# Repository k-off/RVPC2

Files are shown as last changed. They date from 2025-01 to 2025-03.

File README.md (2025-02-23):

# RVPC2

Inspired by [OLIMEX RVPC](https://github.com/OLIMEX/RVPC) project, I decided to create a #higher-faster-stronger version.

Key differences:

|Feature|V1|V2|
|-|-|-|
|**MCU**|||
|Model|CH32V003F4P6|CH32X035G8R6|
|Pins|8|28|
|RAM|2k|20k|
|ROM|16k|64k|
|USB| X | **V** |
|**Display**|||
|Color|mono (1-bit)| 8 (3-bit)|
|Communication| X | **V** |
|**Ports**|||
|PS2| **V** | X |
|USB| X | **2.0 FS** |
|Audio| X | 3.5mm jack |
|Storage| X | Micro-SD |
|Power| 5V, 5mm barrel| 5V, USB-C PD|

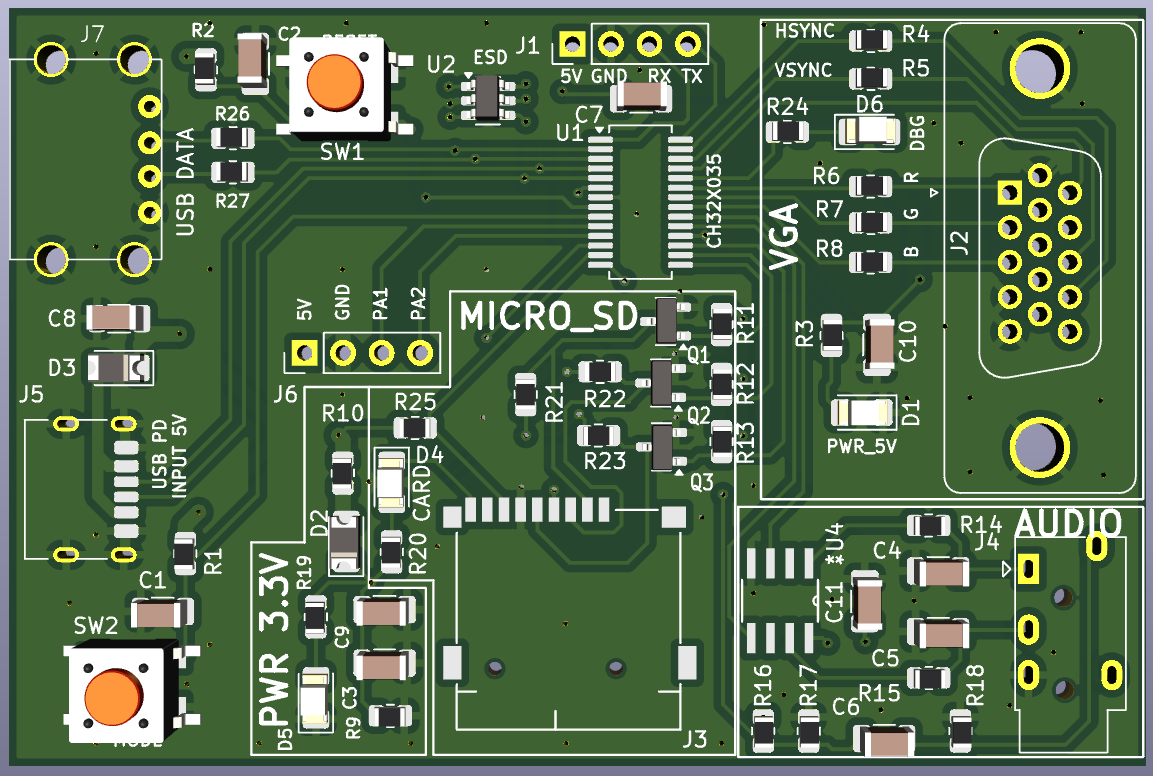
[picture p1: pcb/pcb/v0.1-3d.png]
preview


## Build tools:

 - IDE of your choice:
   - [MounRiver](http://www.mounriver.com/download)
   - [VSCode](https://code.visualstudio.com/download)
 - Compiler (in case it isn't bundled with ide): [riscv-none-elf-gcc-xpack](https://xpack-dev-tools.github.io/riscv-none-elf-gcc-xpack/docs/install/) instructions page

## Troubleshoot

In case MounRiver build fails with `Bad CPU type in executable`, try:
 - right click on project name in project explorer (left top corner of the window)
 - select `Properties`
 - `Build Settings`->`Target Processor`->`RISC-V Compiler`: select `WCH Toolchain(GCC12)` or newer

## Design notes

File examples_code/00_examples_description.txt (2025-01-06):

Nanjing Qinheng Microelectronics Co., Ltd. 2024.11

https://wch-ic.com

Directory
  |
  |-- SRC  
  |      |-- Core: core system header file
  |      |-- Debug: delay fuction, UART debugging source file and header file
  |      |-- Ld: ld file  
  |      |-- Peripheral: basic peripheral driver source file and header file
  |      |-- Startup: startup file.
  |      |      |-- startup_ch32x035.S
  |-- ADC
  |      |-- ADC_DMA: ADC DMA sampling routines
  |      |-- AnalogWatchdog: analog watchdog routine
  |      |-- Auto_Injection: automatic injection mode routine
  |      |-- Discontinuous_mode: discontinuous mode routine
  |      |-- ExtLines_Trigger: external lines trigger ADC conversion routine
  |-- APPLICATION
  |      |-- WS2812_LED: Operating WS2812 via SPI\PWM Routine
  |-- DMA
  |      |-- DMA_MEM2MEM: Memory to memory mode routine
  |      |-- DMA_MEM2PERIP: Memory to peripheral mode, and peripheral to memory mode routine, see peripheral sub-routines
  |-- EXTI
  |      |-- EXTI0: External Interrupt Routine
  |-- FLASH
  |      |-- FLASH_Program: FLASH erase/read/write, and fast programming 
  |-- FreeRTOS
  |      |-- FreeRTOS_Core: FreeRTOS migration routines
  |-- GPIO
  |      |-- GPIO_Toggle: GPIO routines 
  |-- HarmonyOS
  |      |-- LiteOS_m: HarmonyOS migration routine
  |-- I2C
  |      |-- I2C_7bit_Mode: 7-bit addressing mode, master/slave mode, transceiver routine
  |      |-- I2C_10bit_Mode: 10-bit addressing mode, master/slave mode transceiver routine
  |      |-- I2C_DMA: I2C DMA, master/slave mode transceiver routine
  |      |-- I2C_EEPROM: I2C interface routine to operate EEPROM peripheral 
  |      |-- I2C_PEC: PEC error check, master/slave mode transceiver routine
  |      |-- I2C_7bit_Interrupt_Mode: Send/receive routines using interrupts
  |-- INT
  |      |-- Interrupt_VTF: VTF IRQ interrupt routine   
  |-- IAP: IAP upgrade routine, including the Hex to Bin tool and IAP upgrade tool  
  |      |-- USB_UART: USB+UART IAP routine    
  |-- IWDG
  |      |-- IWDG: Independent Watchdog routine 
  |-- PIOC
  |      |-- 1-Wire
  |      |      |-- 1-Wire: 1 wire operate WS2812 and DS1820
  |      |      |-- Ams
  |      |      |      |-- PIOC_INC.ASM: PIOC assembly header file 
  |      |      |      |-- RGB1W.ASM: Signal line compilation source file
  |      |      |      |-- RGB1W.BAT: Compile Scripts
  |      |      |      |-- RGB1W.BIN: Compile the generated data files
  |      |      |      |-- RGB1W.LST: Compile the generated list file
  |      |      |      |-- RGB1W_inc.h: Data files converted to hex files
  |      |-- PIOC_UART
  |      |      |-- PIOC_UART: PIOC simulates UART
  |      |      |-- Ams
  |      |      |      |-- PIOC_INC.ASM: PIOC assembly header file 
  |      |      |      |-- PIOC_UART.ASM: UART compilation source file
  |      |      |      |-- PIOC_UART.BAT: Compile Scripts
  |      |      |      |-- PIOC_UART.BIN: Compile the generated data files
  |      |      |      |-- PIOC_UART.LST: Compile the generated list file
  |      |      |      |-- PIOC_UART_inc.h: Data files converted to hex files 
  |      |-- PIOC_IIC 
  |      |      |-- PIOC_IIC: PIOC simulates IIC
  |      |      |-- Ams
  |      |      |      |-- PIOC_INC.ASM: PIOC assembly header file 
  |      |      |      |-- PIOC_IIC.ASM: IIC compilation source file
  |      |      |      |-- PIOC_IIC.BAT: Compile Scripts
  |      |      |      |-- PIOC_IIC.BIN: Compile the generated data files
  |      |      |      |-- PIOC_IIC.LST: Compile the generated list file
  |      |      |      |-- PIOC_IIC_inc.h: Data files converted to hex files
  |      |-- PIOC_Single_Wire
  |      |      |-- PIOC_Single_Wire: Single-wire debug interface to read and write external chip RAM data
  |      |      |-- Ams
  |      |      |      |-- PIOC_INC.ASM: PIOC assembly header file 
  |      |      |      |-- PIOC_Single_Wire.ASM: IIC compilation source file
  |      |      |      |-- PIOC_Single_Wire.BAT: Compile Scripts
  |      |      |      |-- PIOC_Single_Wire.BIN: Compile the generated data files
  |      |      |      |-- PIOC_Single_Wire.LST: Compile the generated list file
  |      |      |      |-- PIOC_Single_Wire_inc.h: Data files converted to hex files
  |      |-- PIOC_NEC
  |      |      |-- PIOC_NEC: PIOC Infrared Remote Control Routine
  |      |      |-- Ams
  |      |      |      |-- PIOC_INC.ASM: PIOC assembly header file 
  |      |      |      |-- PIOC_NEC.ASM: NEC compilation source file
  |      |      |      |-- PIOC_NEC.BAT: Compile Scripts
  |      |      |      |-- PIOC_NEC.BIN: Compile the generated data files
  |      |      |      |-- PIOC_NEC.LST: Compile the generated list file
  |      |      |      |-- PIOC_NEC.h: Data files converted to hex files
  |      |-- Tool_Manual
  |      |      |-- Manual
  |      |      |      |-- CHRISC8B.PDF: RISC8B Core Microcontroller Instruction Set
  |      |      |      |-- PIOC.PDF: Programmable Protocol I/O Microcontroller PIOC Handbook
  |      |      |-- Tool
  |      |      |      |-- BIN_HEX.EXE: BIN to HEX file conversion tool
  |      |      |      |-- WASM53B.EXE: RISC8B microcontroller assembly tool for compiling assembly source programs into instruction code target data
  |      |-- PIOC instructions for use.pdf
  |-- OPA
  |      |-- CMP: Comparator routines
  |      |-- CMP_TIM2: Timer 2 Capture Comparator Routine
  |      |-- OPA: OPA as voltage follower output routine
  |      |-- OPA_BKIN: OPA brake routine
  |      |-- OPA_IRQ: OPA interrupt routine
  |      |-- OPA_PGA: OPA PGA routine
  |      |-- OPA_Poll: OPA Poll routine
  |      |-- OPA_Reset: OPA Reset routine
  |-- PWR
  |      |-- Sleep_Mode: low power, sleep mode routine
  |      |-- Standby_Mode: low power, standby mode routine
  |      |-- Stop_Mode: low power, stop mode routine
  |      |-- PVD_Wakeup：STOP mode PVD wakeup MCU Routine
  |      |-- PVD_VoltageJudger：PVD voltage Judger Routine
  |-- PMP
  |      |-- PMP：Physical memory protection Routine
  |-- RCC
  |      |-- Get_CLK: Get system-HCLK-AHB1-AHB2 clock routine   
  |      |-- MCO: MCO pin clock output routine    
  |-- RT-Thread
  |      |-- rt_thread_Core: RT-Thread migration routine  
  |-- RunInRam
  |      |-- RunInRAM_Select: Some programs run routines in RAM.
  |-- SDI_Printf
  |      |-- SDI_Printf: debug interface SDI, virtual serial port.     
  |-- SPI
  |      |-- 1Lines_half-duplex: single wire half duplex mode, master/slave mode, data transceiver
  |      |-- 2Lines_FullDuplex: two-wire full duplex mode, master/slave mode, data transceiver
  |      |-- FullDuplex_HardNSS: Hardware NSS mode, master/slave mode, data transceiver
  |      |-- SPI_CRC: CRC error check and master/slave mode transceiver routine
  |      |-- SPI_DMA: SPI DMA, master/slave mode transceiver routine
  |      |-- SPI_FLASH: SPI interface operation flash peripheral routine
  |-- TencentOS
  |      |-- TencentOS: TencentOS migration routine  
  |-- TIM
  |      |-- Clock_Select: clock source selection routine
  |      |-- ComplementaryOutput_DeadTime: complementary output and deadband insertion mode routines
  |      |-- ExtTrigger_Start_Two_Timer: external trigger routines to start two timers synchronously
  |      |-- Input_Capture: input capture routine
  |      |-- One_Pulse: single pulse output routine
  |      |-- Output_Compare_Mode: output comparison mode routine
  |      |-- PWM_Output: PWM output routine
  |      |-- Synchro_ExtTrigger: slave mode routine, including reset mode, gating mode and trigger mode
  |      |-- Synchro_Timer: timer synchronization mode
  |      |-- TIM_DMA: timer DMA routines
  |      |-- Encode:Timer encoder mode routines
  |      |-- TIM_INT:Timer interrupt routines
  |-- TOUCHKEY
  |      |-- TKey: TouchKey Detection Routine 
  |-- USART
  |      |-- USART_DMA: USART DMA, master/slave mode transceiver routine
  |      |-- USART_HalfDuplex: single wire half duplex mode, master/slave mode transceiver routine
  |      |-- USART_HardwareFlowControl: hardware flow control mode, master/slave mode, transceiver routine
  |      |-- USART_Interrupt: USART interrupt routine, master/slave mode transceiver routine
  |      |-- USART_MultiProcessorCommunication: multiprocessor communication mode routine
  |      |-- USART_Polling: polling transceiver mode, master/slave transceiver routine
  |      |-- USART_Printf: USART Print debugging routine
  |      |-- USART_SynchronousMode: synchronous mode, master/slave mode, transceiver routine
  |      |-- USART_Idle_Recv: Serial port using DMA for indeterminate length reception routine
  |      |-- USART_SmartCard: Serial port smart card routine
  |-- USB
  |      |-- USBFS
  |      |      |-- DEVICE
  |      |      |      |-- CH372: Simulates a custom USB device (CH372 device) with endpoints 1, 3, 5 down and 2, 4, 6 up. Data down from endpoint 1 is uploaded from endpoint 2 and not reversed, and data down from endpoint 3, 5  is uploaded from endpoint 4, 6 and reversed.
  |      |      |      |-- Compatibility_HID: Simulates HID devices, with data transmitted up and down through the serial port.
  |      |      |      |-- CompositeKM: Simulate keyboard and mouse, use IO to simulate keystrokes, while simulated data can be uploaded through serial port 2.
  |      |      |      |-- CompositeKM_LowSpeed: Simulate low speed keyboard and mouse, use IO to simulate keystrokes, while simulated data can be uploaded through serial port 2.
  |      |      |      |-- SimulateCDC: Simulate a CDC serial port and use serial port 2 to send and receive.
  |      |      |      |-- SimulateCDC-HID: Simulate a CDC serial port, use serial port 2 to send and receive, HID interrupt endpoints to send and receive data to reverse and upload.  
  |      |      |      |-- MSC_U-Disk: Simulate a USB flash drive function.
  |      |      |-- HOST_KM: The host operates the keypad, gets the data of the endpoints uploaded by the keypad and prints it, supports U-port under level 1 hub
  |      |      |-- HOST_MTP_FileSystem: Enumeration process of a USB host to a device that supports MTP and PTP protocols, supports MTP and PTP protocols, and reads its files
  |      |      |-- Host_Udisk: USB host operation USB disk routine 
  |      |      |-- Udisk_Lib: U disk file system library file  
  |-- USBPD
  |      |-- USBPD_SNK: PD SNK routine
  |      |-- USBPD_SRC: PD SRC routine    
  |-- WWDG
  |      |-- WWDG: Window Watchdog Routine

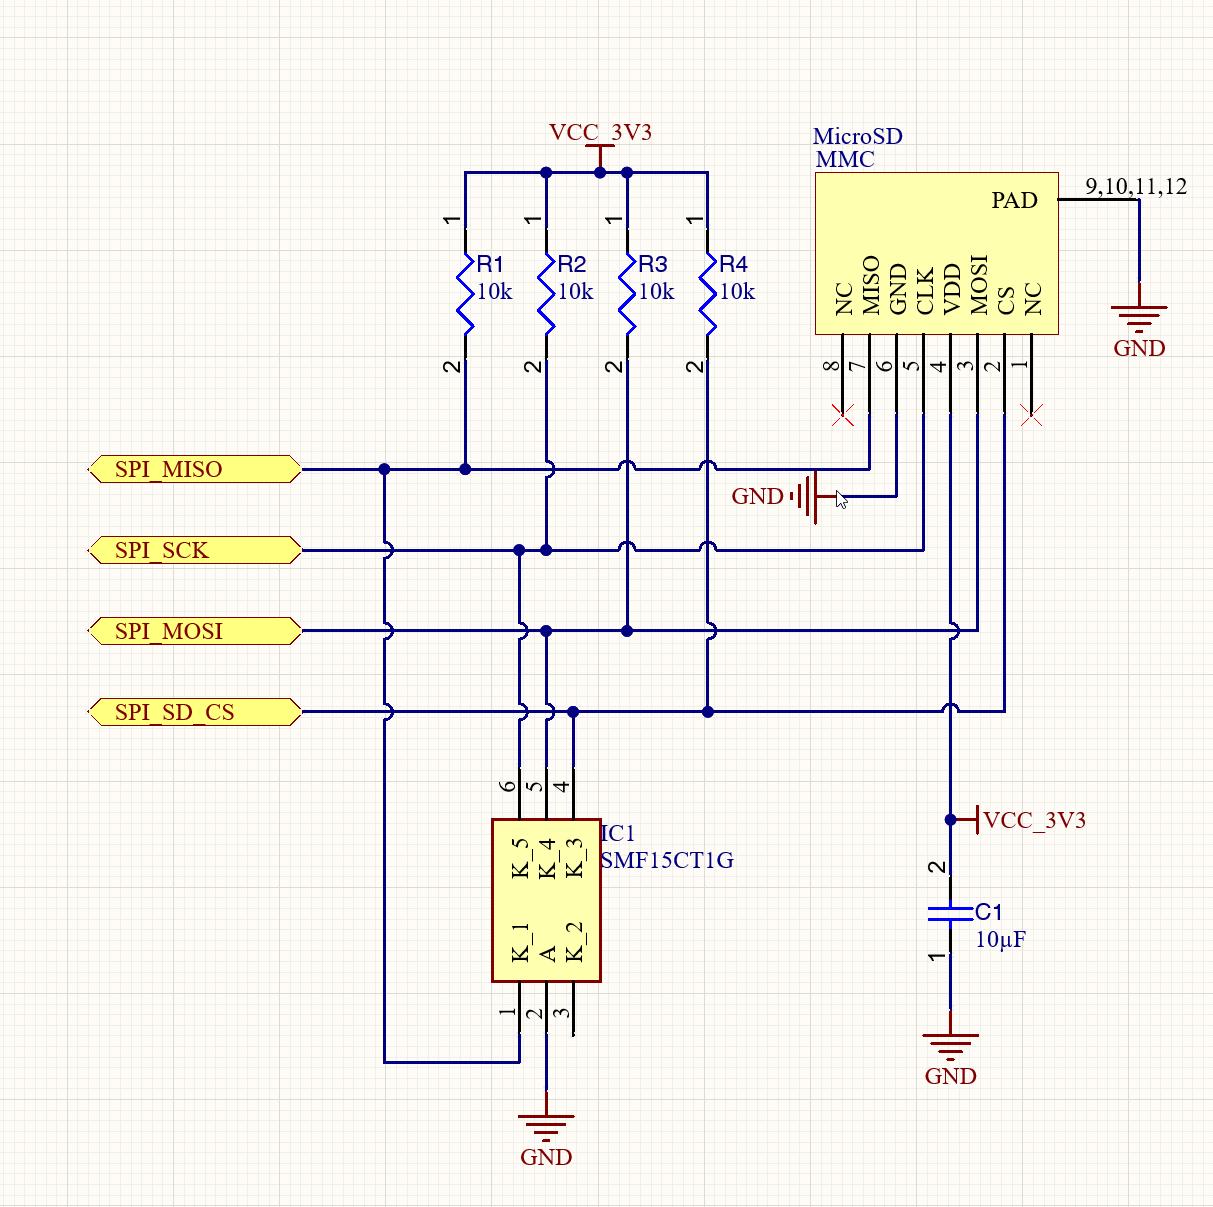
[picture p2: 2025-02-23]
pcb/sd_card_variant.jpg

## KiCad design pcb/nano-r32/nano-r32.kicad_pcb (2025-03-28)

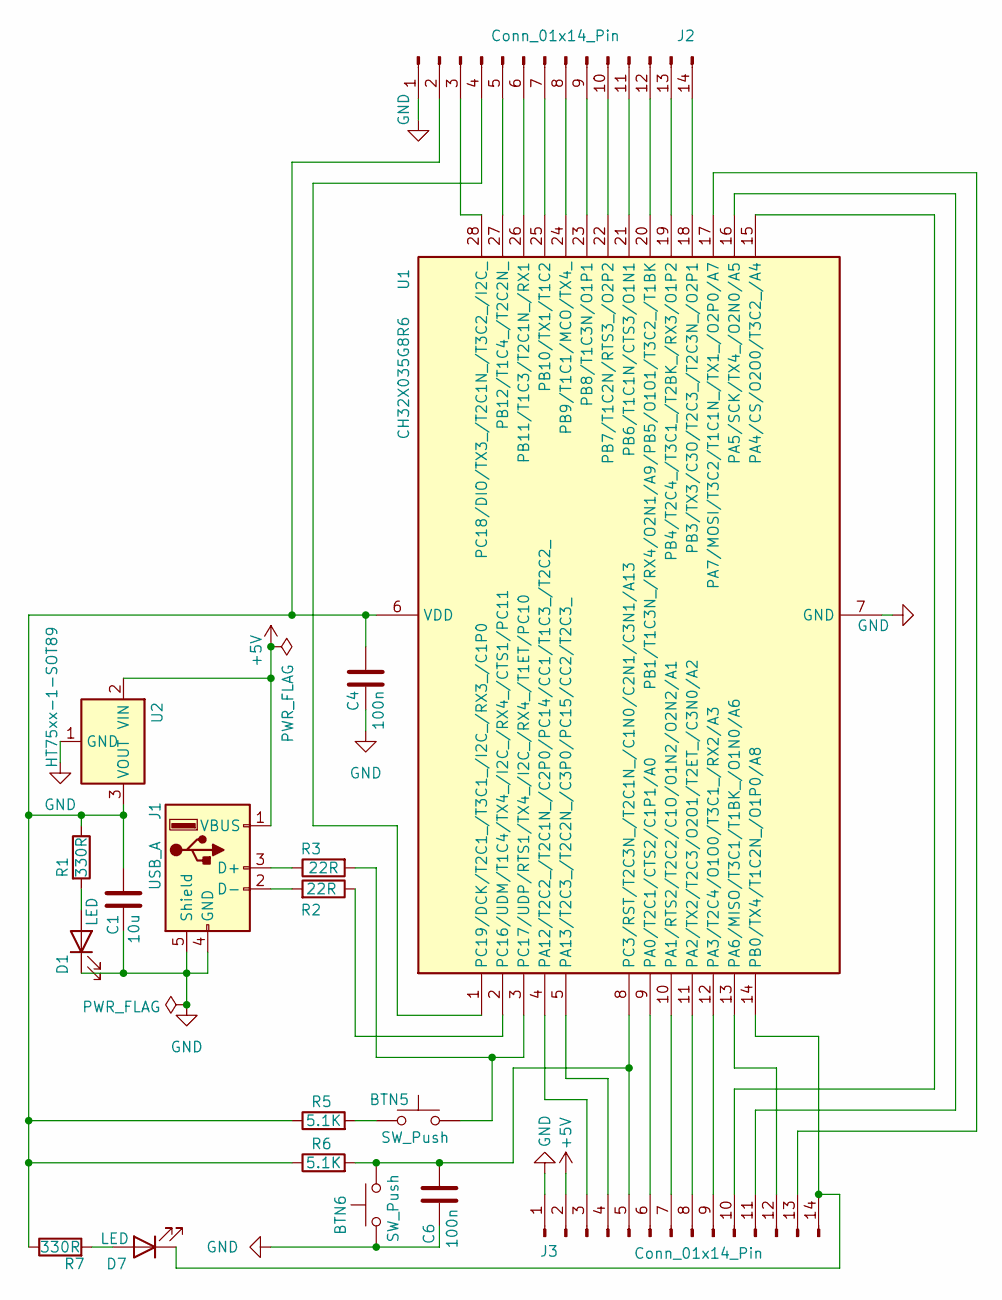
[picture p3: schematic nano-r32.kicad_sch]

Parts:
BTN5, BTN6: SW_Push; SW_SPST_5x5x1.5
C1: 10u; C_1206_3216Metric
C4, C6: 100n; C_1206_3216Metric
D1, D7: LED; D_1206_3216Metric
J1: USB_A; USB2_A_Female_Short_14.6x10
J2, J3: Conn_01x14_Pin; PinSocket_1x14_P2.54mm_Vertical
R1, R7: 330R; R_0805_2012Metric
R2, R3: 22R; R_0805_2012Metric
R5, R6: 5.1K; R_0805_2012Metric
U1: CH32X035G8R6; QSOP-28_3.9x9.9mm_P0.635mm
U2: HT75xx-1-SOT89; SOT-89-3

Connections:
+5V: J1.1 (VBUS), J3.2, U2.2 (VIN)
GND: BTN6.1, C1.1, C4.2, C6.2, D1.1 (K), J1.4 (GND), J1.5 (Shield), J2.1, J3.1, U1.7 (GND), U2.1 (GND)
unnamed: BTN5.1, R5.2
unnamed: D1.2 (A), R1.2
unnamed: D7.2 (A), R7.2
unnamed: D7.1 (K), J3.14, U1.14 (PB0/TX4/T1C2N_/O1P0/A8)
unnamed: J1.3 (D+), R3.1
unnamed: J1.2 (D-), R2.2
unnamed: C1.2, C4.1, J2.2, R1.1, R5.1, R6.1, R7.1, U1.6 (VDD), U2.3 (VOUT)
unnamed: J2.3, U1.28 (PC18/DIO/TX3_/T2C1N_/T3C2_/I2C_)
unnamed: J2.4, U1.1 (PC19/DCK/T2C1_/T3C1_/I2C_/RX3_/C1P0)
unnamed: J2.5, U1.27 (PB12/T1C4_/T2C2N_)
unnamed: J2.6, U1.26 (PB11/T1C3/T2C1N_/RX1)
unnamed: J2.7, U1.25 (PB10/TX1/T1C2)
unnamed: J2.8, U1.24 (PB9/T1C1/MCO/TX4_)
unnamed: J2.9, U1.23 (PB8/T1C3N/O1P1)
unnamed: J2.10, U1.22 (PB7/T1C2N/RTS3_/O2P2)
unnamed: J2.11, U1.21 (PB6/T1C1N/CTS3/O1N1)
unnamed: J2.12, U1.20 (PB1/T1C3N_/RX4/O2N1/A9/PB5/O1O1/T3C2_/T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)
unnamed: J2.13, U1.19 (PB4/T2C4_/T3C1_/T2BK_/RX3/O1P2)
unnamed: J2.14, U1.18 (PB3/TX3/C3O/T2C3_/T2C3N_/O2P1)
unnamed: J3.3, U1.4 (PA12/T2C2_/T2C1N_/C2P0/PC14/CC1/T1C3_/T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)
unnamed: J3.4, U1.5 (PA13/T2C3_/T2C2N_/C3P0/PC15/CC2/T2C3_)
unnamed: BTN6.2, C6.1, J3.5, R6.2, U1.8 (PC3/RST/T2C3N_/T2C1N_/C1N0/C2N1/C3N1/A13)
unnamed: J3.6, U1.9 (PA0/T2C1/CTS2/C1P1/A0)
unnamed: J3.7, U1.10 (PA1/RTS2/T2C2/C1O/O1N2/O2N2/A1)
unnamed: J3.8, U1.11 (PA2/TX2/T2C3/O2O1/T2ET_/C3N0/A2)
unnamed: J3.9, U1.12 (PA3/T2C4/O1O0/T3C1_/RX2/A3)
unnamed: J3.10, U1.15 (PA4/CS/O2O0/T3C2_/A4)
unnamed: J3.11, U1.16 (PA5/SCK/TX4_/O2N0/A5)
unnamed: J3.12, U1.13 (PA6/MISO/T3C1/T1BK_/O1N0/A6)
unnamed: J3.13, U1.17 (PA7/MOSI/T3C2/T1C1N_/TX1_/O2P0/A7)
unnamed: R2.1, U1.2 (PC16/UDM/T1C4/TX4_/I2C_/RX4_/CTS1/PC11)
unnamed: BTN5.2, R3.2, U1.3 (PC17/UDP/RTS1/TX4_/I2C_/RX4_/T1ET/PC10)

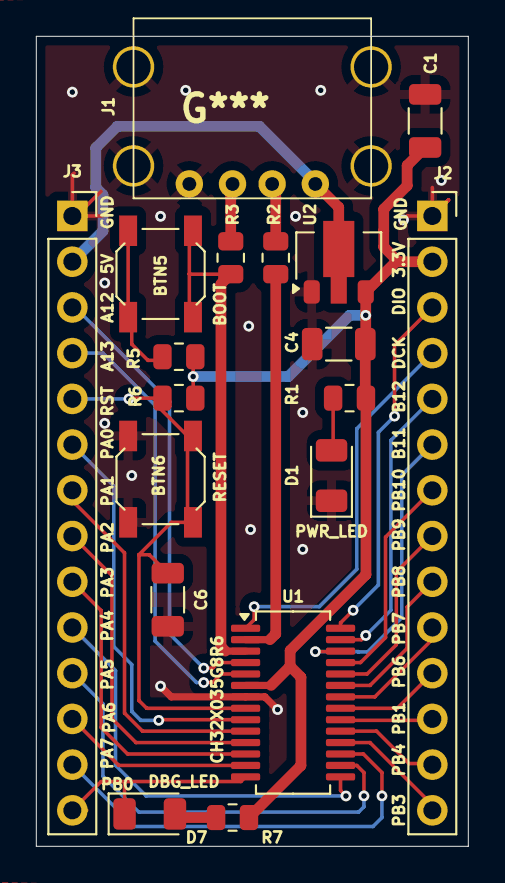
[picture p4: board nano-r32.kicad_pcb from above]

Board: 2 copper layers, 24.0 x 45.0 mm, 18 parts (0 on the bottom side), 34 nets.

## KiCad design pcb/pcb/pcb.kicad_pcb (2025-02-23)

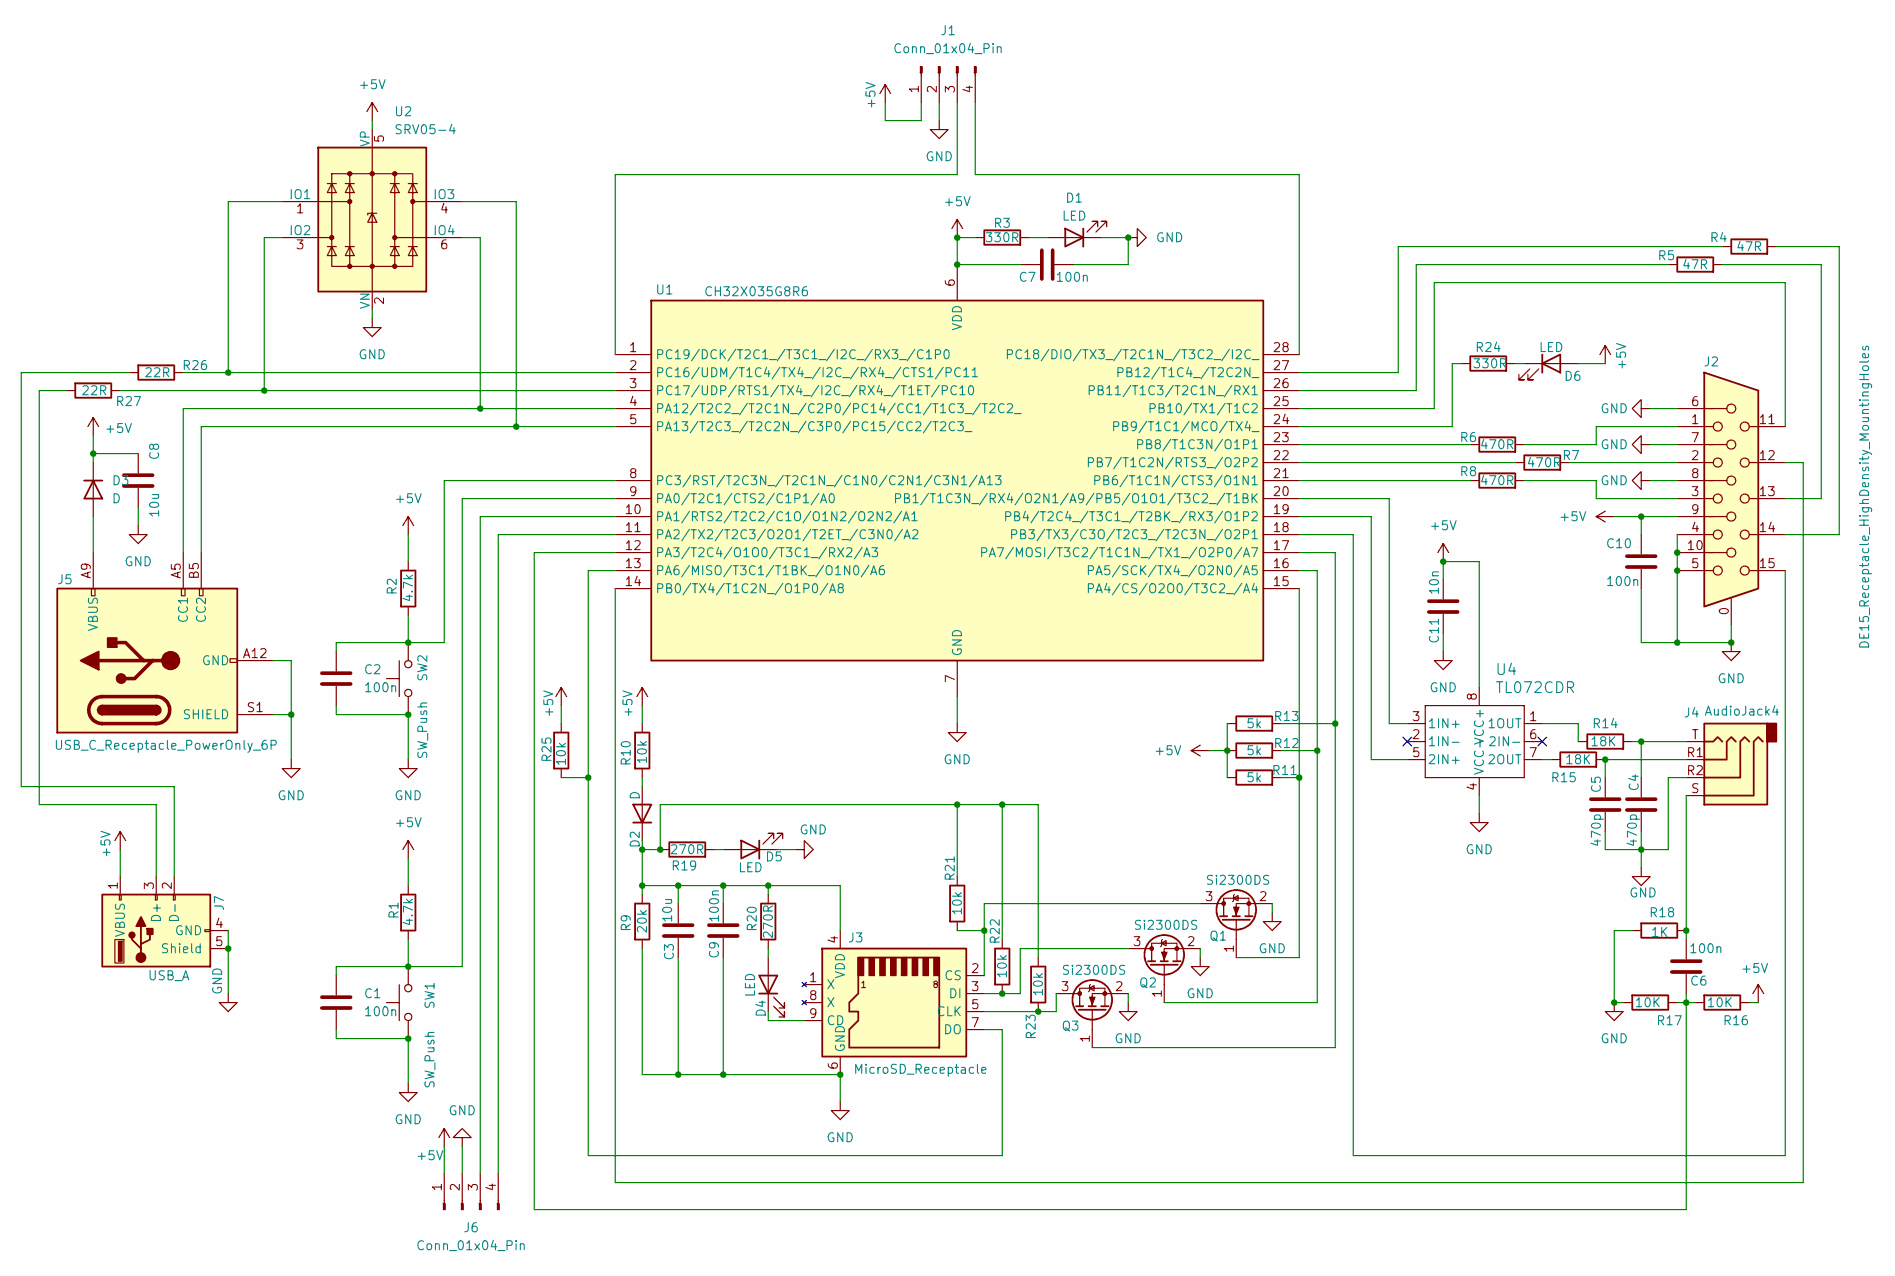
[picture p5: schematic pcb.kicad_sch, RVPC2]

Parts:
C1, C2, C6, C7, C9, C10: 100n; C_1206_3216Metric
C3, C8: 10u; C_1206_3216Metric
C4, C5: 470p; C_1206_3216Metric
C11: 10n; C_1206_3216Metric
D1, D4, D5, D6: LED; LED_1206_3216Metric
D2, D3: D; D_1206_3216Metric
J1, J6: Conn_01x04_Pin; PinHeader_1x04_P2.54mm_Vertical
J2: DE15_Receptacle_HighDensity_MountingHoles; DSUB-15-HD_Female_Vertical_P2.29x1.98mm_MountingHoles
J3: MicroSD_Receptacle; Micro_SD_9pin_push_push
J4: AudioJack4; Jack_3.5mm_PJ320E_Horizontal
J5: USB_C_Receptacle_PowerOnly_6P; USB_C_Receptacle_HRO_TYPE-C-31-M-17
J7: USB_A; USB2_A_Female_Short_14.6x10
Q1, Q2, Q3: Si2300DS; SOT-23
R1, R2: 4.7k; R_0805_2012Metric
R3, R24: 330R; R_0805_2012Metric
R4, R5: 47R; R_0805_2012Metric
R6, R7, R8: 470R; R_0805_2012Metric
R9: 20k; R_0805_2012Metric
R10, R21, R22, R23, R25: 10k; R_0805_2012Metric
R11, R12, R13: 5k; R_0805_2012Metric
R14, R15: 18K; R_0805_2012Metric
R16, R17: 10K; R_0805_2012Metric
R18: 1K; R_0805_2012Metric
R19, R20: 270R; R_0805_2012Metric
R26, R27: 22R; R_0805_2012Metric
SW1, SW2: SW_Push; SW_SPST_5x5_4pin
U1: CH32X035G8R6; QSOP-28_3.9x9.9mm_P0.635mm
U2: SRV05-4; SOT-23-6
U4: TL072CDR; D8

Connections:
+5V: C7.1, C8.1, C10.1, C11.1, D3.1 (K), D6.2 (A), J1.1, J2.9, J6.1, J7.1 (VBUS), R1.1, R2.1, R3.1, R10.1, R11.1, R12.1, R13.1, R16.1, R25.1, U1.6 (VDD), U2.5 (VP), U4.8 (VCC+)
GND: C1.2, C2.2, C3.2, C4.2, C5.2, C7.2, C8.2, C9.2, C10.2, C11.2, D1.1 (K), D5.1 (K), J1.2, J2.0, J2.4, J2.5, J2.6, J2.7, J2.8, J2.10, J3.6 (GND), J4.R2, J5.A12 (GND), J5.B12 (GND), J5.S1 (SHIELD), J6.2, J7.4 (GND), J7.5 (Shield), Q1.2 (S), Q2.2 (S), Q3.2 (S), R9.2, R17.2, R18.2, SW1.1, SW2.1, U1.7 (GND), U2.2 (VN), U4.4 (VCC-)
unnamed: C4.1, J4.T, R14.2
unnamed: C5.1, J4.R1, R15.2
unnamed: C6.1, J4.S, R18.1
unnamed: D1.2 (A), R3.2
unnamed: D2.2 (A), R10.2
unnamed: C3.1, C9.1, D2.1 (K), J3.4 (VDD), R9.1, R19.1, R20.1, R21.1, R22.1, R23.1
unnamed: D3.2 (A), J5.A9 (VBUS), J5.B9 (VBUS)
unnamed: D4.2 (A), R20.2
unnamed: D4.1 (K), J3.9 (CD)
unnamed: D5.2 (A), R19.2
unnamed: D6.1 (K), R24.2
unnamed: J1.3, U1.1 (PC19/DCK/T2C1_/T3C1_/I2C_/RX3_/C1P0)
unnamed: J1.4, U1.28 (PC18/DIO/TX3_/T2C1N_/T3C2_/I2C_)
unnamed: J2.1, R6.2
unnamed: J2.2, R7.2
unnamed: J2.3, R8.2
unnamed: J2.13, R5.2
unnamed: J2.14, R4.2
unnamed: J3.5 (CLK), Q3.3 (D), R23.2
unnamed: J3.2 (CS), Q1.3 (D), R21.2
unnamed: J3.3 (DI), Q2.3 (D), R22.2
unnamed: J3.7 (DO), R25.2, U1.13 (PA6/MISO/T3C1/T1BK_/O1N0/A6)
unnamed: J5.A5 (CC1), U1.4 (PA12/T2C2_/T2C1N_/C2P0/PC14/CC1/T1C3_/T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), U2.6 (IO4)
unnamed: J5.B5 (CC2), U1.5 (PA13/T2C3_/T2C2N_/C3P0/PC15/CC2/T2C3_), U2.4 (IO3)
unnamed: J6.3, U1.10 (PA1/RTS2/T2C2/C1O/O1N2/O2N2/A1)
unnamed: J6.4, U1.11 (PA2/TX2/T2C3/O2O1/T2ET_/C3N0/A2)
unnamed: J7.3 (D+), R27.2
unnamed: J7.2 (D-), R26.2
unnamed: Q1.1 (G), R11.2, U1.15 (PA4/CS/O2O0/T3C2_/A4)
unnamed: Q2.1 (G), R12.2, U1.16 (PA5/SCK/TX4_/O2N0/A5)
unnamed: Q3.1 (G), R13.2, U1.17 (PA7/MOSI/T3C2/T1C1N_/TX1_/O2P0/A7)
unnamed: C1.1, R1.2, SW1.2, U1.9 (PA0/T2C1/CTS2/C1P1/A0)
unnamed: C6.2, R16.2, R17.1, U1.12 (PA3/T2C4/O1O0/T3C1_/RX2/A3)
unnamed: J2.12, U1.14 (PB0/TX4/T1C2N_/O1P0/A8)
unnamed: U1.20 (PB1/T1C3N_/RX4/O2N1/A9/PB5/O1O1/T3C2_/T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), U4.3 (1IN+)
unnamed: J2.15, U1.18 (PB3/TX3/C3O/T2C3_/T2C3N_/O2P1)
unnamed: U1.19 (PB4/T2C4_/T3C1_/T2BK_/RX3/O1P2), U4.5 (2IN+)
unnamed: R8.1, U1.21 (PB6/T1C1N/CTS3/O1N1)
unnamed: R7.1, U1.22 (PB7/T1C2N/RTS3_/O2P2)
unnamed: R6.1, U1.23 (PB8/T1C3N/O1P1)
unnamed: R24.1, U1.24 (PB9/T1C1/MCO/TX4_)
unnamed: J2.11, U1.25 (PB10/TX1/T1C2)
unnamed: R5.1, U1.26 (PB11/T1C3/T2C1N_/RX1)
unnamed: R4.1, U1.27 (PB12/T1C4_/T2C2N_)
unnamed: C2.1, R2.2, SW2.2, U1.8 (PC3/RST/T2C3N_/T2C1N_/C1N0/C2N1/C3N1/A13)
unnamed: R26.1, U1.2 (PC16/UDM/T1C4/TX4_/I2C_/RX4_/CTS1/PC11), U2.1 (IO1)
unnamed: R27.1, U1.3 (PC17/UDP/RTS1/TX4_/I2C_/RX4_/T1ET/PC10), U2.3 (IO2)
unnamed: R14.1, U4.1 (1OUT)
unnamed: R15.1, U4.7 (2OUT)

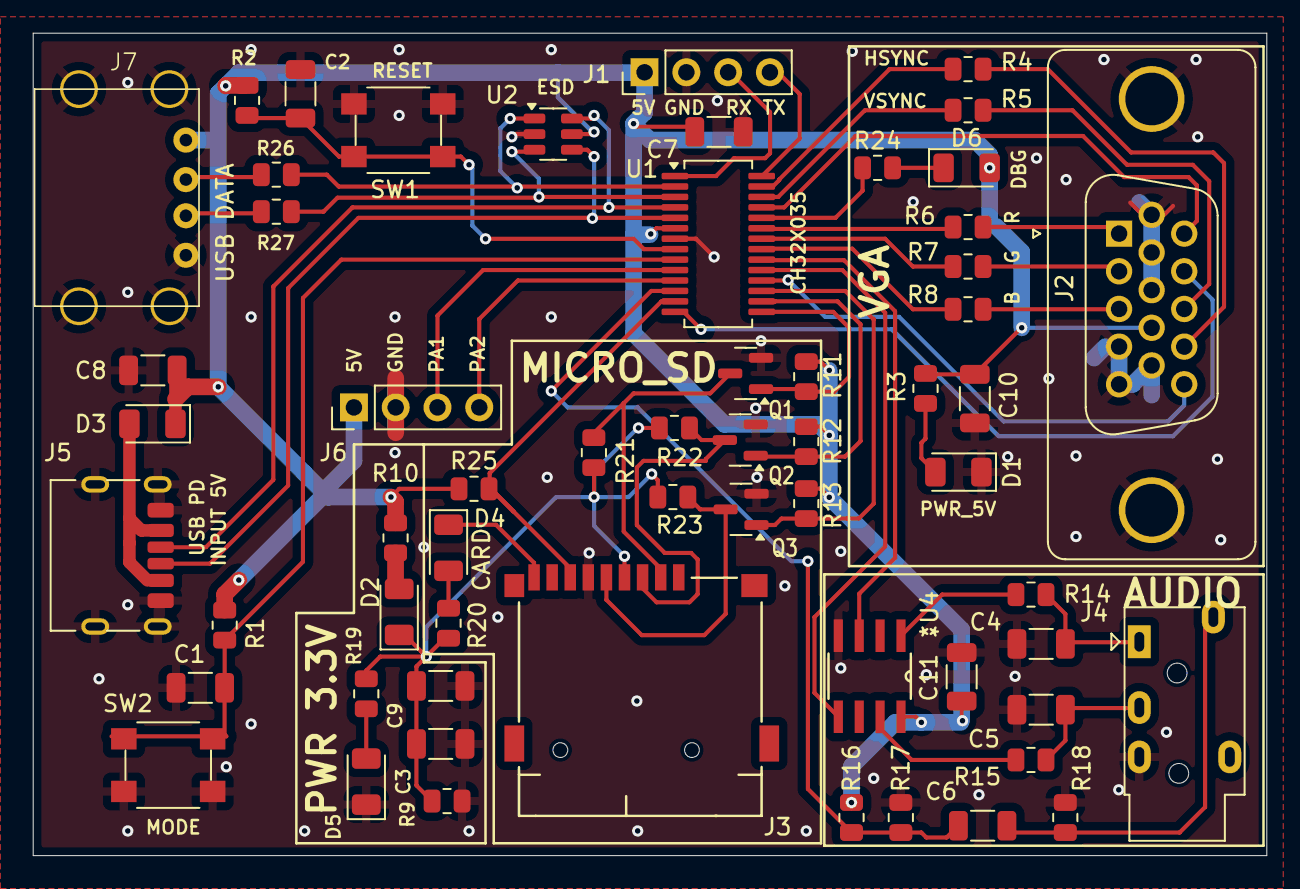
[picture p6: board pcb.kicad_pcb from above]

Board: 2 copper layers, 75.0 x 50.0 mm, 59 parts (0 on the bottom side), 51 nets.

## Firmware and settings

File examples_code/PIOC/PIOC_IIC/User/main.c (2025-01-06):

/********************************** (C) COPYRIGHT *******************************
 * File Name          : main.c
 * Author             : WCH
 * Version            : V1.0.0
 * Date               : 2023/12/26
 * Description        : Main program body.
*********************************************************************************
* Copyright (c) 2021 Nanjing Qinheng Microelectronics Co., Ltd.
* Attention: This software (modified or not) and binary are used for
* microcontroller manufactured by Nanjing Qinheng Microelectronics.
*******************************************************************************/

/*
 *@Note
 *
 *PC18---SCL
 *PC19---SDA
 *
 *
 */

#include "debug.h"
#include "string.h"

void PIOC_IRQHandler(void) __attribute__((interrupt("WCH-Interrupt-fast")));
void PIOC_IIC_SLAVE(uint8_t *p_send_addr,uint16_t send_len,uint8_t *p_receive_addr,uint16_t receive_len);

/* I2C Mode Definition */
#define HOST_MODE     0
#define SLAVE_MODE    1

/* I2C Communication Mode Selection */
#define I2C_MODE      HOST_MODE
//#define I2C_MODE   SLAVE_MODE

/* Global define */
#define     IIC_SFR_ADDR1  ((uint8_t *)&(PIOC->D8_DATA_REG8))
#define     IIC_SFR_ADDR2  ((uint8_t *)&(PIOC->D8_DATA_REG16))
#define     IIC_SFR_ADDR3  ((uint8_t *)&(PIOC->D8_DATA_REG24))
#define   R16_DATA_REG4_5  (*((volatile unsigned short *)(PIOC_SFR_BASE+0x24))) // RW/RW, data buffer 4~5
#define     PIOC_TIM_PSC2      ((uint8_t)0x07)
#define     PIOC_TIM_PSC4      ((uint8_t)0x06)
#define     PIOC_TIM_PSC8      ((uint8_t)0x05)
#define     PIOC_TIM_PSC16     ((uint8_t)0x04)
#define     PIOC_TIM_PSC32     ((uint8_t)0x03)
#define     PIOC_TIM_PSC128    ((uint8_t)0x02)
#define     PIOC_TIM_PSC512    ((uint8_t)0x01)
#define     PIOC_TIM_PSC2048   ((uint8_t)0x00)

uint8_t  PIOC_IIC_FLAG=0;
uint16_t PIOC_IIC_RemainLEN0=0;
uint16_t PIOC_IIC_RemainLEN1=0;
uint16_t PIOC_IIC_RemainLEN2=0;
uint16_t PIOC_IIC_RemainLEN3=0;
uint8_t  *PIOC_IIC_BUF_ADDR0 = NULL;
uint8_t  *PIOC_IIC_BUF_ADDR1 = NULL;
uint8_t  *PIOC_IIC_BUF_ADDR2 = NULL;
uint8_t  *PIOC_IIC_BUF_ADDR3 = NULL;

uint8_t rx_buf[100]={0};

__attribute__((aligned(16)))  const unsigned char PIOC_CODE[] =
{0x00,0x00,0xE2,0x61,0xFF,0x0F,0x00,0x00,0x00,0x00,0x00,0x00,0x00,0x00,0x00,0x00,   /* ...a............ */
 0x00,0x00,0x30,0x00,0x03,0x70,0x00,0x00,0x03,0x70,0x00,0x00,0x03,0x70,0x00,0x00,   /* ..0..p...p...p.. */
 0x03,0x70,0x00,0x00,0xFF,0x2C,0x00,0x00,0x0A,0x30,0x30,0x00,0x21,0x02,0x07,0x10,   /* .p...,...00.!... */
 0x20,0x02,0x06,0x10,0x30,0x00,0x14,0x00,0x1E,0x02,0x0B,0x48,0x0B,0x49,0x0F,0x23,   /* ....0......H.I.# */
 0x03,0x41,0x03,0x43,0x26,0x51,0x03,0x4B,0x08,0x28,0x27,0x10,0x28,0x24,0x16,0x70,   /* .A.C&Q.K.('.($.p */
 0x05,0x28,0x0A,0x70,0x0B,0x41,0x05,0x28,0x0A,0x70,0x21,0x02,0x05,0x10,0x06,0x4D,   /* .(.p.A.(.p!....M */
 0x06,0x4C,0x23,0x02,0x1F,0x10,0x17,0x00,0xBF,0x00,0x16,0x00,0x17,0x00,0xBE,0x00,   /* .L#............. */
 0x16,0x00,0x17,0x00,0xBD,0x00,0x16,0x00,0x17,0x00,0xBC,0x00,0x16,0x00,0x17,0x00,   /* ................ */
 0xBB,0x00,0x16,0x00,0x17,0x00,0xBA,0x00,0x16,0x00,0x17,0x00,0xB9,0x00,0x16,0x00,   /* ................ */
 0x17,0x00,0x03,0x53,0x1F,0x40,0xB8,0x00,0x16,0x00,0x17,0x00,0x0A,0x41,0x16,0x00,   /* ...S.@.......A.. */
 0x1F,0x00,0xFD,0x3C,0x03,0x5B,0x87,0x60,0x17,0x00,0x0B,0x41,0x0A,0x49,0x22,0x02,   /* ...<.[.`...A.I". */
 0x1F,0x10,0xBF,0x00,0x16,0x00,0x17,0x00,0xBE,0x00,0x16,0x00,0x17,0x00,0xBD,0x00,   /* ................ */
 0x16,0x00,0x17,0x00,0xBC,0x00,0x16,0x00,0x17,0x00,0xBB,0x00,0x16,0x00,0x17,0x00,   /* ................ */
 0xBA,0x00,0x16,0x00,0x17,0x00,0xB9,0x00,0x16,0x00,0x17,0x00,0xB8,0x00,0x16,0x00,   /* ................ */
 0x17,0x00,0x0A,0x41,0x16,0x00,0x1F,0x00,0xFD,0x3C,0x23,0x58,0xCA,0x60,0x17,0x00,   /* ...A.....<#X.`.. */
 0x0B,0x49,0x0A,0x49,0x0B,0x40,0x06,0x45,0x06,0x44,0x01,0x28,0x0A,0x70,0x06,0x4D,   /* .I.I.@.E.D.(.p.M */
 0x06,0x4C,0x0B,0x48,0x16,0x00,0x06,0x45,0x06,0x44,0x03,0x43,0x28,0x60,0x1F,0x58,   /* .L.H...E.D.C(`.X */
 0xCA,0x60,0x17,0x00,0x0B,0x40,0x06,0x45,0x06,0x44,0x0B,0x28,0x0A,0x70,0x06,0x4D,   /* .`...@.E.D.(.p.M */
 0x06,0x4C,0x0B,0x48,0x17,0x00,0x0A,0x41,0x16,0x00,0xFF,0x00,0x17,0x00,0x16,0x00,   /* .L.H...A........ */
 0xFE,0x00,0x17,0x00,0x16,0x00,0xFD,0x00,0x17,0x00,0x16,0x00,0xFC,0x00,0x17,0x00,   /* ................ */
 0x16,0x00,0xFB,0x00,0x17,0x00,0x16,0x00,0xFA,0x00,0x17,0x00,0x16,0x00,0xF9,0x00,   /* ................ */
 0x17,0x00,0x24,0x15,0x24,0x04,0x03,0x52,0x25,0x15,0x16,0x00,0xF8,0x00,0x24,0x02,   /* ..$.$..R%.....$. */
 0x25,0x0A,0xC2,0x34,0x17,0x00,0x0B,0x41,0x0A,0x49,0x1F,0x02,0x01,0x10,0x16,0x00,   /* %..4...A.I...... */
 0x27,0x15,0x92,0x30,0x03,0x51,0x28,0x24,0x02,0x28,0x03,0x1B,0x08,0x28,0x27,0x10,   /* '..0.Q($.(...('. */
 0x1C,0x4F,0x92,0x60,0x17,0x00,0x0B,0x49,0x0A,0x49,0x1F,0x02,0x01,0x10,0x16,0x00,   /* .O.`...I.I...... */
 0x1C,0x4F,0xFD,0x60,0x17,0x00,0x0B,0x41,0x0A,0x49,0x01,0x02,0x1F,0x10,0xBF,0x00,   /* .O.`...A.I...... */
 0x16,0x00,0x17,0x00,0x03,0x70,0xBE,0x00,0x16,0x00,0x17,0x00,0xBD,0x00,0x16,0x00,   /* .....p.......... */
 0x17,0x00,0xBC,0x00,0x16,0x00,0x17,0x00,0xBB,0x00,0x16,0x00,0x17,0x00,0xBA,0x00,   /* ................ */
 0x16,0x00,0x17,0x00,0xB9,0x00,0x16,0x00,0x27,0x15,0xED,0x30,0x03,0x51,0x28,0x24,   /* ........'..0.Q($ */
 0x02,0x28,0x03,0x1B,0x08,0x28,0x27,0x10,0x1C,0x4F,0x17,0x00,0xB8,0x00,0x16,0x00,   /* .(...('..O...... */
 0x24,0x15,0x24,0x04,0x03,0x52,0x25,0x15,0x17,0x00,0x0A,0x41,0x16,0x00,0x1F,0x00,   /* $.$..R%....A.... */
 0xFD,0x3C,0x24,0x02,0x25,0x0A,0xFD,0x34,0xCA,0x60,0x17,0x00,0x0B,0x41,0x0A,0x49,   /* .<$.%..4.`...A.I */
 0x16,0x00,0x06,0x45,0x06,0x44,0x01,0x28,0x0A,0x70,0x0B,0x49,0x1B,0x60,0x03,0x41,   /* ...E.D.(.p.I.`.A */
 0x03,0x43,0x28,0x24,0x0B,0x48,0x0B,0x49,0x0C,0x23,0x16,0x00,0x1F,0x00,0x0D,0x39,   /* .C($.H.I.#.....9 */
 0x15,0x00,0x03,0x70,0x1E,0x00,0x0D,0x39,0x08,0x28,0x27,0x10,0x23,0x40,0x17,0x00,   /* ...p...9.('.#@.. */
 0x16,0x00,0xFF,0x00,0x17,0x00,0x16,0x00,0xFE,0x00,0x17,0x00,0x16,0x00,0xFD,0x00,   /* ................ */
 0x17,0x00,0x16,0x00,0xFC,0x00,0x17,0x00,0x16,0x00,0xFB,0x00,0x17,0x00,0x16,0x00,   /* ................ */
 0xFA,0x00,0x17,0x00,0x16,0x00,0xF9,0x00,0x1F,0x40,0x1F,0x02,0x23,0x0B,0x07,0x31,   /* .........@..#..1 */
 0x17,0x00,0x16,0x00,0xF8,0x00,0x03,0x53,0x73,0x61,0x1F,0x58,0x3D,0x61,0x26,0x51,   /* .......Ssa.X=a&Q */
 0x07,0x61,0x17,0x00,0x0B,0x41,0x0A,0x49,0xAE,0x61,0x26,0x51,0x43,0x61,0x17,0x00,   /* .a...A.I.a&QCa.. */
 0x0B,0x41,0x0A,0x49,0x79,0x61,0x17,0x00,0x0B,0x41,0x0A,0x49,0x16,0x00,0x17,0x00,   /* .A.Iya...A.I.... */
 0x0A,0x41,0x16,0x00,0xFF,0x00,0x17,0x00,0x16,0x00,0xFE,0x00,0x17,0x00,0x16,0x00,   /* .A.............. */
 0xFD,0x00,0x17,0x00,0x16,0x00,0xFC,0x00,0x17,0x00,0x16,0x00,0xFB,0x00,0x17,0x00,   /* ................ */
 0x16,0x00,0xFA,0x00,0x17,0x00,0x16,0x00,0xF9,0x00,0x17,0x00,0x16,0x00,0xF8,0x00,   /* ................ */
 0x1F,0x02,0x22,0x0B,0x07,0x31,0x17,0x00,0x0B,0x41,0x0A,0x49,0x16,0x00,0x17,0x00,   /* .."..1...A.I.... */
 0x0A,0x41,0x16,0x00,0xFF,0x00,0x1F,0x00,0x89,0x39,0x0B,0x5F,0x6D,0x61,0x1E,0x00,   /* .A.......9._ma.. */
 0x8B,0x39,0x03,0x4B,0x17,0x61,0x1F,0x58,0x07,0x61,0x17,0x00,0x0B,0x41,0x0A,0x49,   /* .9.K.a.X.a...A.I */
 0xAE,0x61,0x23,0x48,0x16,0x00,0x17,0x00,0x0A,0x41,0x16,0x00,0xFF,0x00,0x1F,0x00,   /* .a#H.....A...... */
 0x8A,0x3D,0x03,0x70,0x0B,0x57,0x82,0x61,0x1E,0x00,0x8B,0x39,0x26,0x4A,0x1C,0x4F,   /* .=.p.W.a...9&J.O */
 0x07,0x61,0x23,0x48,0x17,0x00,0x16,0x00,0xFE,0x00,0x17,0x00,0x16,0x00,0xFD,0x00,   /* .a#H............ */
 0x17,0x00,0x16,0x00,0xFC,0x00,0x17,0x00,0x16,0x00,0xFB,0x00,0x17,0x00,0x16,0x00,   /* ................ */
 0xFA,0x00,0x17,0x00,0x16,0x00,0xF9,0x00,0x17,0x00,0x16,0x00,0xF8,0x00,0x1F,0x02,   /* ................ */
 0x01,0x10,0x17,0x00,0x0B,0x41,0x0A,0x49,0x27,0x15,0x79,0x31,0x03,0x51,0x28,0x24,   /* .....A.I'.y1.Q($ */
 0x02,0x28,0x03,0x1B,0x08,0x28,0x27,0x10,0x1C,0x4F,0x79,0x61,0x23,0x40,0x1C,0x4F,   /* .(...('..Oya#@.O */
 0x38,0x24,0x03,0x49,0x16,0x00,0x17,0x00,0x04,0x00,0x01,0x0A,0x1F,0x10,0x01,0x01,   /* 8$.I............ */
 0x01,0x02,0xBF,0x00,0x0A,0x49,0x16,0x00,0x17,0x00,0xBE,0x00,0x16,0x00,0x17,0x00,   /* .....I.......... */
 0xBD,0x00,0x16,0x00,0x17,0x00,0xBC,0x00,0x16,0x00,0x17,0x00,0xBB,0x00,0x16,0x00,   /* ................ */
 0x17,0x00,0xBA,0x00,0x16,0x00,0x17,0x00,0xB9,0x00,0x16,0x00,0x27,0x15,0xD7,0x31,   /* ............'..1 */
 0x03,0x51,0x28,0x24,0x02,0x28,0x03,0x1B,0x08,0x28,0x27,0x10,0x1C,0x4F,0x17,0x00,   /* .Q($.(...('..O.. */
 0xB8,0x00,0x16,0x00,0x17,0x00,0x0A,0x41,0x16,0x00,0x1F,0x00,0xB2,0x39,0x26,0x4A,   /* .......A.....9&J */
 0x1C,0x4F,0x07,0x61,0x00,0x00,0x00,0x00,0x14,0x00,0x26,0x58,0x07,0x61,0x1B,0x60,   /* .O.a......&X.a.` */
 0xE2,0x61,0xE9,0x61};  /* .a.a */


u8 pbuf1[32] = {
    0x55, 0x08, 0x09,
    0x0A, 0x0B, 0x0C,
    0x0D, 0x0E, 0x00,
    0x01, 0x02, 0x03,
    0x04, 0x05, 0x05,
    0x00,
    0x01, 0x02, 0x03,
    0x04, 0x05, 0x06,
    0x07, 0x08, 0x09,
    0x0A, 0x0B, 0x0C,
    0x0D, 0x0E, 0x0F,
    0x55,

};

/*********************************************************************
 * @fn      GPIO_Toggle_INIT
 *
 * @brief   Initializes GPIOA.0
 *
 * @return  none
 */
void GPIO_Toggle_INIT(void)
{
    GPIO_InitTypeDef GPIO_InitStructure = {0};

    RCC_APB2PeriphClockCmd(RCC_APB2Periph_GPIOA, ENABLE);
    GPIO_InitStructure.GPIO_Pin = GPIO_Pin_0;
    GPIO_InitStructure.GPIO_Mode = GPIO_Mode_Out_PP;
    GPIO_InitStructure.GPIO_Speed = GPIO_Speed_50MHz;
    GPIO_Init(GPIOA, &GPIO_InitStructure);
}

/*********************************************************************
 * @fn      PIOC_INIT
 *
 * @brief   Initializes PIOC
 *
 * @return  none
 */
void PIOC_INIT(void)
{
    GPIO_InitTypeDef GPIO_InitStructure = {0};

    RCC_APB2PeriphClockCmd(RCC_APB2Periph_GPIOC|RCC_APB2Periph_AFIO, ENABLE);
    GPIO_PinRemapConfig(GPIO_Remap_SWJ_Disable, ENABLE);
    GPIO_InitStructure.GPIO_Pin = GPIO_Pin_18|GPIO_Pin_19;
    GPIO_InitStructure.GPIO_Mode = GPIO_Mode_AF_PP;
    GPIO_InitStructure.GPIO_Speed = GPIO_Speed_50MHz;
    GPIO_Init(GPIOC, &GPIO_InitStructure);

    NVIC_EnableIRQ( PIOC_IRQn );                                        //enable PIOC interrupt
    NVIC_SetPriority(PIOC_IRQn,0xf0);

    memcpy((uint8_t *)(PIOC_SRAM_BASE),PIOC_CODE,sizeof(PIOC_CODE));    // load code for PIOC
    R8_SYS_CFG |= RB_MST_RESET;                                         // reset PIOC
    R8_SYS_CFG = RB_MST_IO_EN1 | RB_MST_IO_EN0;                         // enable IO0&IO1
    R8_SYS_CFG |= RB_MST_CLK_GATE;                                      // open PIOC clock
}


/*********************************************************************
 * @fn      PIOC_IRQHandler
 *
 * @brief   This function handles PIOC exception.
 *
 * @return  none
 */
void PIOC_IRQHandler( void )
{
    uint8_t *addr_target = NULL;
    uint8_t *addr_data = NULL;
    uint8_t data_len = 0;
    if((R8_SYS_CFG&RB_INT_REQ)!=RESET)
    {
        //Data read mode
        if((R8_DATA_REG3 & 0X01)!=RESET)
        {
            addr_target = PIOC_IIC_BUF_ADDR0;
            if(PIOC_IIC_FLAG==1)
            {
                addr_data = IIC_SFR_ADDR1;
                PIOC_IIC_FLAG=2;
            }
            else if(PIOC_IIC_FLAG==2)
            {
                addr_data = IIC_SFR_ADDR2;
                PIOC_IIC_FLAG=1;
            }
            if(PIOC_IIC_RemainLEN0>8)
            {
                if((R8_DATA_REG6 & 0x04)!=RESET)
                    data_len = 8-R8_DATA_REG7;
                else
                    data_len = 8;
                PIOC_IIC_BUF_ADDR0 += 8;
                PIOC_IIC_RemainLEN0 -= 8;
            }
            else if(PIOC_IIC_RemainLEN0>0)
            {
                if((R8_DATA_REG6 & 0x04)!=RESET)
                    data_len = 8-R8_DATA_REG7;
                else
                    data_len = PIOC_IIC_RemainLEN0;
                PIOC_IIC_RemainLEN0 = 0;
                PIOC_IIC_FLAG = 0;
                PIOC_IIC_BUF_ADDR0 = NULL;
            }

        }
        //Data write Mode
        else
        {
            addr_data = PIOC_IIC_BUF_ADDR1;
            if(PIOC_IIC_FLAG==1)
            {
                addr_target = IIC_SFR_ADDR1;
                PIOC_IIC_FLAG=2;
            }
            else if(PIOC_IIC_FLAG==2)
            {
                addr_target = IIC_SFR_ADDR2;
                PIOC_IIC_FLAG=1;
            }
            if(PIOC_IIC_RemainLEN1>8)
            {
                data_len = 8;
                PIOC_IIC_BUF_ADDR1 += 8;
                PIOC_IIC_RemainLEN1 -= 8;
            }
            else if(PIOC_IIC_RemainLEN1>0)
            {
                data_len = PIOC_IIC_RemainLEN1;
                PIOC_IIC_RemainLEN1 = 0;
                PIOC_IIC_FLAG = 0;
                PIOC_IIC_BUF_ADDR1 = NULL;
            }
        }
        memcpy( addr_target, addr_data, data_len );
        //Slave reception completed or transmission completed,
        if((R8_DATA_REG6 & 0x04)!=RESET)
        {
            R8_DATA_REG6 &= ~(0X04);
            //Rewrite the data to be sent and received
            PIOC_IIC_SLAVE(PIOC_IIC_BUF_ADDR3,PIOC_IIC_RemainLEN3,PIOC_IIC_BUF_ADDR2,PIOC_IIC_RemainLEN2);
        }
        R8_CTRL_RD=11;    // False write any value to R8_CTRL_RD, clear interrupt flag
    }

}

/*********************************************************************
 * @fn      PIOC_IIC_INIT
 *
 * @brief   Initializes PIOC_IIC,
 *
 * @param   arr - 0~255.
 *          psc - PIOC_TIM_PSC2
 *                PIOC_TIM_PSC4
 *                PIOC_TIM_PSC8
 *                PIOC_TIM_PSC16
 *                PIOC_TIM_PSC32
 *                PIOC_TIM_PSC128
 *                PIOC_TIM_PSC512
 *                PIOC_TIM_PSC2048
 *          address - In 7-bit address mode, bits 1-7 are valid addresses
 *                    In 10 bit address mode, bits 0-9 are valid addresses
 *
 * @return  none
 */
void PIOC_IIC_INIT(u8 arr, u8 psc, u16 address)
{
    uint32_t tmp=0;
    tmp |= (uint32_t)(((0XFF-arr)<<8)|psc);
    if(address>0XFF)
    {
        tmp |= (uint32_t)(((0xf0 << 8) | ((address & 0x0300)<<1) | (address & 0xff))<<16);
        R8_DATA_REG6 |= (1<<1);
    }
    else
    {
        tmp |= (uint32_t)((address & 0xfe)<<24);
        R8_DATA_REG6 &= ~(1<<1);
    }
    R32_DATA_REG0_3 = tmp;
}

/*********************************************************************
 * @fn      PIOC_IIC_SEND
 *
 * @brief   Host send data.
 *
 * @param   p_source_addr - data.
 *          total_bytes - total data number(byte).
 *
 * @return  none
 */
void PIOC_IIC_SEND(uint8_t *p_source_addr,uint16_t total_bytes)
{
    if(total_bytes<=16)
    {
        memcpy( IIC_SFR_ADDR1, p_source_addr, total_bytes );
        PIOC_IIC_FLAG = 0;
        PIOC_IIC_RemainLEN1 = 0;
    }
    else
    {
        memcpy( IIC_SFR_ADDR1, p_source_addr, 16 );
        PIOC_IIC_FLAG = 1;
        PIOC_IIC_RemainLEN1 = total_bytes-16;
        PIOC_IIC_BUF_ADDR1 = p_source_addr+16;
    }
    R16_DATA_REG4_5 = total_bytes;
    R8_DATA_REG6 |= 0x01;
    R8_DATA_REG3 &= ~(0x01);        //write
    R8_CTRL_WR = 0X33;              // To R8_CTRL_WR write any value,then start
}

/*********************************************************************
 * @fn      PIOC_IIC_Receive
 *
 * @brief   Host receive data
 *
 * @param   p_source_addr - data.
 *          total_bytes - total data number(byte).
 *
 * @return  none
 */
void PIOC_IIC_Receive(uint8_t *p_source_addr,uint16_t total_bytes)
{
    PIOC_IIC_BUF_ADDR0 = p_source_addr;
    PIOC_IIC_RemainLEN0 = total_bytes;
    PIOC_IIC_FLAG = 1;
    R16_DATA_REG4_5 = total_bytes;
    R8_DATA_REG6 |= 0x01;
    R8_DATA_REG3 |= 0x01;           //read
    R8_CTRL_WR = 0X33;              // To R8_CTRL_WR write any value,then start
}

/*********************************************************************
 * @fn      PIOC_IIC_SLAVE
 *
 * @brief   slave mode
 *
 * @param   p_send_addr - send data.
 *          send_len - total data number(byte).
 *          p_receive_addr - receive data.
 *          receive_len - receive maximum(byte).
 *
 * @return  none
 */
void PIOC_IIC_SLAVE(uint8_t *p_send_addr,uint16_t send_len,uint8_t *p_receive_addr,uint16_t receive_len)
{
    PIOC_IIC_BUF_ADDR0 = PIOC_IIC_BUF_ADDR2 = p_receive_addr;
    PIOC_IIC_RemainLEN0 = PIOC_IIC_RemainLEN2 = receive_len;
    PIOC_IIC_BUF_ADDR3 = p_send_addr;
    PIOC_IIC_RemainLEN3 = send_len;
    if(send_len<=8)
    {
        memcpy( IIC_SFR_ADDR3, p_send_addr, send_len );
        PIOC_IIC_FLAG = 0;
        PIOC_IIC_RemainLEN1 = 0;
    }
    else
    {
        memcpy( IIC_SFR_ADDR3, p_send_addr, 8 );
        PIOC_IIC_FLAG = 1;
        PIOC_IIC_RemainLEN1 = send_len-8;
        PIOC_IIC_BUF_ADDR1 = p_send_addr+8;
    }
    R8_DATA_REG6 &= ~(0x01);
    R8_CTRL_WR = 0X33;
}
/*********************************************************************
 * @fn      main
 *
 * @brief   Main program.
 *
 * @return  none
 */
int main(void)
{
    int i=0;
    int j=0;
    NVIC_PriorityGroupConfig(NVIC_PriorityGroup_1);
    SystemCoreClockUpdate();
    Delay_Init();
    USART_Printf_Init(921600);
    printf("SystemClk:%d\r\n", SystemCoreClock);
    printf( "ChipID:%08x\r\n", DBGMCU_GetCHIPID() );
    printf("GPIO Toggle TEST\r\n");
    GPIO_Toggle_INIT();
    PIOC_INIT();
    PIOC_IIC_INIT(60-1, PIOC_TIM_PSC2, 0X332);    //  48M/2/60=400K

#if( I2C_MODE == HOST_MODE )

    PIOC_IIC_SEND(pbuf1,sizeof(pbuf1));
    Delay_Ms(100);
    PIOC_IIC_Receive(rx_buf,32);
    Delay_Ms(100);
#elif ( I2C_MODE == SLAVE_MODE )

    PIOC_IIC_SLAVE(pbuf1,sizeof(pbuf1),rx_buf,100);
    Delay_Ms(1000);

#endif
    for(j=0;j<32;j++)
    {
        printf("%x\r\n",rx_buf[j]);
    }

    while(1)
    {
        Delay_Ms(500);
        GPIO_WriteBit(GPIOA, GPIO_Pin_0, (i == 0) ? (i = Bit_SET) : (i = Bit_RESET));
    }
}

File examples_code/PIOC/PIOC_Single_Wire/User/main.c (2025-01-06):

/********************************** (C) COPYRIGHT *******************************
 * File Name          : main.c
 * Author             : WCH
 * Version            : V1.0.0
 * Date               : 2024/06/05
 * Description        : Main program body.
*********************************************************************************
* Copyright (c) 2021 Nanjing Qinheng Microelectronics Co., Ltd.
* Attention: This software (modified or not) and binary are used for
* microcontroller manufactured by Nanjing Qinheng Microelectronics.
*******************************************************************************/

/*
 *@Note
 *
 *PC18---SWDIO,needs to connected  a 1k pull-up resistor
 *
 */

#include "debug.h"
#include "string.h"

void PIOC_IRQHandler(void) __attribute__((interrupt("WCH-Interrupt-fast")));
void PIOC_Single_Wire_SingleWrite(uint8_t addr,uint32_t data);

#define  Timebase_def  1

//#define    Timebase_1X  0
#define    Timebase_2X  Timebase_def
//#define    Timebase_4X  2
//#define    Timebase_8X  3

#ifdef Timebase_1X
uint8_t  Timebase = Timebase_1X;
#elif  Timebase_4X
uint8_t  Timebase = Timebase_4X;
#elif  Timebase_8X
uint8_t  Timebase = Timebase_8X;
#else
uint8_t  Timebase = Timebase_def;
#endif

uint8_t Timebase_Flag=0;
uint8_t dbg_flag = 0;


volatile uint16_t Send_RemainLEN=0;
volatile uint16_t Receive_RemainLEN=0;
volatile uint32_t *Send_BUF_ADDR = NULL;
volatile uint32_t *Receive_BUF_ADDR = NULL;



uint32_t pbuf1[16] = {
    0x55aa0000, 0xaa550001,
    0x55aa55aa, 0xaa55aa55,
    0x55aa55aa, 0xaa55aa55,
    0x090A0B0C, 0x0D0E0F55,
    0x5508090A, 0x0B0C0D0E,
    0x00010203, 0x04050500,
    0x01020304, 0x05060708,
    0x090A0B0C, 0x0D0E0F55,
};
uint32_t buf[16];

const u32 PIOC_Single_Wire_R_W_blk[8]={ 0xe0000537, 0x0f450513, 0xf693414c, 0x8563ffc5, 0x411000d5, 0xa019c290, 0xc1104290, 0xc14c0591};
const u32 PIOC_Single_Wire_R_32bit[8]={ 0x7b251073, 0x7b359073, 0xe0000537, 0x0f852583, 0x2a23418c, 0x25730eb5, 0x25f37b20, 0x90027b30};
const u32 PIOC_Single_Wire_R_16bit[8]={ 0x7b251073, 0x7b359073, 0xe0000537, 0x0f852583, 0x0005d583, 0x0eb52a23, 0x7b202573, 0x7b3025f3};
const u32 PIOC_Single_Wire_R_8bit[8]={ 0x7b251073, 0x7b359073, 0xe0000537, 0x0f852583, 0x0005c583, 0x0eb52a23, 0x7b202573, 0x7b3025f3};
const u32 PIOC_Single_Wire_W_32bit[8]={ 0x7b251073, 0x7b359073, 0xe0000537, 0x0f852583, 0x0f452503, 0x2573c188, 0x25f37b20, 0x90027b30};
const u32 PIOC_Single_Wire_W_16bit[8]={ 0x7b251073, 0x7b359073, 0xe0000537, 0x0f852583, 0x0f452503, 0x00a59023, 0x7b202573, 0x7b3025f3};
const u32 PIOC_Single_Wire_W_8bit[8]={ 0x7b251073, 0x7b359073, 0xe0000537, 0x0f852583, 0x0f452503, 0x00a58023, 0x7b202573, 0x7b3025f3};

__attribute__((aligned(16)))  const unsigned char PIOC_CODE[] =
{0x00,0x00,0xF4,0x60,0xFF,0x0F,0x04,0x00,0x07,0x10,0x03,0x28,0x20,0x09,0x07,0x2B,   /* ...`.......(...+ */
 0x06,0x10,0x30,0x00,0x00,0x00,0x00,0x00,0x00,0x00,0x00,0x00,0x00,0x00,0x00,0x00,   /* ..0............. */
 0x30,0x00,0x0A,0x70,0x00,0x00,0x0A,0x70,0x00,0x00,0x0A,0x70,0x00,0x00,0x0A,0x70,   /* 0..p...p...p...p */
 0x00,0x00,0xFF,0x2C,0x00,0x00,0x11,0x30,0x30,0x00,0x00,0x00,0x00,0x00,0x30,0x00,   /* ...,...00.....0. */
 0x1D,0x70,0x1D,0x70,0x1D,0x70,0x1D,0x70,0x1D,0x70,0x1D,0x70,0x00,0x00,0x00,0x00,   /* .p.p.p.p.p.p.... */
 0x30,0x00,0x20,0x51,0x24,0x70,0x30,0x00,0x20,0x51,0x20,0x70,0x30,0x00,0x20,0x50,   /* 0..Q$p0..Q.p0..P */
 0x2C,0x70,0x20,0x51,0x22,0x70,0x1D,0x70,0x1D,0x70,0x00,0x00,0x00,0x00,0x00,0x00,   /* ,p.Q"p.p.p...... */
 0x00,0x00,0x30,0x00,0x0B,0x40,0x20,0x50,0x29,0x70,0x20,0x51,0x24,0x70,0x03,0x59,   /* ..0..@.P)p.Q$p.Y */
 0x2F,0x70,0x00,0x00,0x0B,0x48,0x1D,0x70,0x1D,0x70,0x1D,0x70,0x03,0x51,0x22,0x14,   /* .p...H.p.p.p.Q". */
 0x03,0x41,0x30,0x00,0x05,0x01,0x0B,0x40,0x0A,0x48,0x06,0x4D,0x20,0x50,0x29,0x70,   /* .A0....@.H.M.P)p */
 0x20,0x51,0x24,0x70,0x03,0x41,0x03,0x28,0x0A,0x40,0x17,0x00,0x06,0x45,0x0C,0x28,   /* .Q$p.A.(.@...E.( */
 0x05,0x0D,0x03,0x52,0x03,0x49,0x03,0x50,0x03,0x49,0x03,0x51,0x22,0x14,0x1D,0x70,   /* ...R.I.P.I.Q"..p */
 0x30,0x00,0x14,0x00,0x1E,0x02,0x03,0x70,0x22,0x01,0x03,0x41,0x0A,0x48,0x04,0x28,   /* 0......p"..A.H.( */
 0x21,0x10,0x20,0x52,0x03,0x49,0x3A,0x70,0x20,0x5A,0x88,0x60,0x23,0x02,0x1F,0x10,   /* !..R.I:p.Z.`#... */
 0x1F,0x56,0x03,0x49,0x3A,0x70,0x1F,0x55,0x03,0x49,0x3A,0x70,0x1F,0x54,0x03,0x49,   /* .V.I:p.U.I:p.T.I */
 0x3A,0x70,0x1F,0x53,0x03,0x49,0x3A,0x70,0x1F,0x52,0x03,0x49,0x3A,0x70,0x1F,0x51,   /* :p.S.I:p.R.I:p.Q */
 0x03,0x49,0x3A,0x70,0x1F,0x50,0x03,0x49,0x3A,0x70,0x20,0x53,0x03,0x49,0x3A,0x70,   /* .I:p.P.I:p.S.I:p */
 0x27,0x22,0x20,0x5B,0xAD,0x60,0x00,0x02,0x1F,0x10,0x1F,0x57,0x03,0x49,0x3A,0x70,   /* '".[.`.....W.I:p */
 0x1F,0x56,0x03,0x49,0x3A,0x70,0x1F,0x55,0x03,0x49,0x3A,0x70,0x1F,0x54,0x03,0x49,   /* .V.I:p.U.I:p.T.I */
 0x3A,0x70,0x1F,0x53,0x03,0x49,0x3A,0x70,0x1F,0x52,0x03,0x49,0x3A,0x70,0x1F,0x51,   /* :p.S.I:p.R.I:p.Q */
 0x03,0x49,0x3A,0x70,0x1F,0x50,0x03,0x49,0x3A,0x70,0x04,0x15,0x21,0x15,0x03,0x5A,   /* .I:p.P.I:p..!..Z */
 0x8B,0x60,0x22,0x50,0x03,0x49,0x3A,0x70,0xD0,0x60,0x1F,0x01,0x4A,0x70,0x03,0x51,   /* .`"P.I:p.`..Jp.Q */
 0x1F,0x4F,0x4A,0x70,0x03,0x51,0x1F,0x4E,0x4A,0x70,0x03,0x51,0x1F,0x4D,0x4A,0x70,   /* .OJp.Q.NJp.Q.MJp */
 0x03,0x51,0x1F,0x4C,0x4A,0x70,0x03,0x51,0x1F,0x4B,0x4A,0x70,0x03,0x51,0x1F,0x4A,   /* .Q.LJp.Q.KJp.Q.J */
 0x4A,0x70,0x03,0x51,0x1F,0x49,0x4A,0x70,0x03,0x51,0x1F,0x48,0x1F,0x02,0x00,0x10,   /* Jp.Q.IJp.Q.H.... */
 0x04,0x15,0x03,0x41,0x21,0x15,0x03,0x5A,0xAD,0x60,0x4A,0x70,0x22,0x50,0x20,0x4C,   /* ...A!..Z.`Jp"P.L */
 0x0A,0x48,0x20,0x56,0x1C,0x4F,0x20,0x4D,0x02,0x28,0x20,0x50,0x01,0x2C,0x20,0x51,   /* .H.V.O.M.(.P.,.Q */
 0x06,0x2C,0x11,0x70,0x61,0x60,0x0B,0x48,0x0A,0x48,0xFF,0x28,0x11,0x70,0x0B,0x40,   /* .,.pa`.H.H.(.p.@ */
 0xFF,0x28,0x11,0x70,0xFF,0x28,0x11,0x70,0xFF,0x28,0x11,0x70,0xFF,0x28,0x11,0x70,   /* .(.p.(.p.(.p.(.p */
 0xFF,0x28,0x11,0x70,0xFF,0x28,0x11,0x70,0xFF,0x28,0x11,0x70,0xCC,0x28,0x11,0x70,   /* .(.p.(.p.(.p.(.p */
 0x0B,0x48,0x01,0x28,0x11,0x70,0x30,0x00,0x00,0x00,0x00,0x00,0xDB,0x70,0x61,0x60,   /* .H.(.p0......pa` */
 0xF4,0x60};    /* .` */
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

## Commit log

2025-01-06 ch32x035 docs and examples
    [CH32X033F-R0-1v0.PcbDoc, CH32X033F-R0.SchDoc, CH32X035C-R0-1v2.PcbDoc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]
2025-01-07 add kicad ch32x035 library
    update GPIO toolchain gcc version to 12
2025-01-08 kicad library: fall back to standard footprints
2025-01-08 cleanup kicad library
2025-01-08 adhere 'ki_fp_filters' values to kicad guidelines
2025-01-08 adhere to kicad library guidelines
2025-01-28 add kicad TL072CDR symbol and footprint
2025-01-28 add kicad pcb templates
    [JLCPCB.kicad_pcb, JLCPCB.sch, PCBWay.kicad_pcb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]
2025-01-28 update CH32X035 kicad lib
2025-01-28 update board
    [pcb.kicad_pcb, pcb.kicad_sch]
2025-02-23 update schematic and pcb
    [pcb.kicad_pcb, pcb.kicad_sch]
2025-02-23 update pcb
    [pcb.kicad_pcb]
2025-03-08 add arduino-like debug board for CH32X035 mcu
    [nano-r32.kicad_pcb, nano-r32.kicad_sch]
2025-03-08 update rvpc2 pcb
2025-03-28 update debug board schematic and layout: add boot button, fix led polarity
    [nano-r32.kicad_pcb, nano-r32.kicad_sch]
